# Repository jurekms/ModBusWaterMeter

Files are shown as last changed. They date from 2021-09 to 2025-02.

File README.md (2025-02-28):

# ModBusWaterMeter
Nakładka na wodomierz zliczająca impulsy ,udostępniająca dane za pomocą protokołu MODBUS poprzez interfejs RS485.
Nakładka na wodomierz zliczająca ilość obrotów dwubarwnej tarczy znajdującej się na panelu odczytowym wodomierza. Optyczny układ przystawki oświetla tarczę obrotową wodomierza światłem IR, które jest odbijane (część lustrzana tarczy) lub pochłaniane (część czarna tarczy), odbita wiązka jest rejestrowana przez fototranzystor z którego sygnał analogowy kierowany jest do komparatora okienkowego zbudowanego na układzie LM393. Na wyjściu komparatora pojawia się sygnał wysoki - gdy fototranzystor jest oświetlony światłem odbitym od tarczy lub niski gdy światło jest pochłaniane przez tarczę i nie dociera do fototranzystora. Tak uformowany sygnał kierowany jest do wejścia D0 mikroprocesora 368. Oprogramowanie rejestruje dwa impulsy na każdy obrót tarczy - dwa przejścia lustro->czarny i czarny->lustro, co daje dwa impulsy na jeden litr przepływu.

szczegóły w opisie  (https://github.com/jurekms/ModBusWaterMeter/blob/main/WIKI/readme.pdf)

# ModBusWaterMeter
Pulse counting water meter overlay, providing data via the MODBUS protocol via the RS485 interface. Overlay on the water meter counting the number of revolutions of the two-color dial located on the reading panel of the water meter. The optical system of the attachment illuminates the rotating disc of the water meter with IR light, which is reflected (mirror part of the dial) or absorbed (black part of the dial), the reflected beam is recorded by the phototransistor from which the analog signal is directed to a window comparator built on the LM393 system. At the output of the comparator there is a high signal - when the phototransistor is illuminated by light reflected from the dial or low when the light is absorbed by the dial and does not reach the phototransistor. The signal formed in this way is directed to the D0 input of the microprocessor 368. The software records two pulses for each rotation of the dial - two mirror->black and black-> mirror transitions, which gives two pulses per one liter of flow.

more in  (https://github.com/jurekms/ModBusWaterMeter/blob/main/WIKI/readme.pdf)

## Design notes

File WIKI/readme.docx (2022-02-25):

Projekt przystawki powstał gdy zaszła konieczność wymiany wodomierzy abonenckich z uwagi na upływający okres ważności legalizacji. Wodomierze eksploatowane są w małej wspólnocie mieszkaniowej której jestem członkiem. Obecny system zdalnego odczytu opiera się na wodomierzach wyposażonych w kontaktrony które przełączane są miniaturowym magnesem umieszczonym na jednym z elementów liczydła, daje to dwa impulsy na jeden litr przepływu. Impulsy są zliczane przez dwa liczniki ośmio wejściowe odczytywane i konfigurowane przy pomocy zapisów i odczytów rejestrów za pośrednictwem protokołu MODBUS na magistrali RS-485. Liczniki są odczytywane co jedną minutę a odczyty porównywane z poprzednio odczytaną wartością, jeśli występuje różnica dane umieszczane są w bazie danych wraz z informacją o dacie i godzinie odczytu. System dodatkowo generuje alarmy wysyłając powiadomienia SMSem, w przypadku gdy ciągły pobór przekracza 10 minut, i w przypadku gdy w ciągu doby nie występuje pobór wody. Do tej pory zebrano ponad 650 tysięcy odczytów, co może służyć do dość szczegółowej analizy zużycia wody, a w zestawieniu z informacją o mieszkańcach czy najemcach lokali użytkowych daje możliwość wykonania dość interesujących analiz. Kilkakrotnie udało się zapobiec niekontrolowanemu poborowi wody głównie na wskutek zablokowania lub nieszczelności spłuczki w WC. Cały system powstał po tym jak w wyniku rocznego rozliczenia zużycia wody, wystąpiła znaczna różnica pomiędzy sumą wskazań wodomierzy abonenckich a wodomierzem Miejskiego Wodociągu. Różnica ta osiągnęła prawie 100m3 co wygenerowało prawie 1000 złotych niedopłaty!.

Jak wspomniano w tym roku mija pięcioletni okres legalizacji wodomierzy. Niestety na rynku nie są już dostępne wodomierze z kontaktronowym impulsatorem. Po analizie oferty dotyczącej wodomierzy z zabudowanymi przystawkami impulsowymi okazało się że wodomierz taki to wydatek około 300 zł. Jednocześnie wydaje się że podobny problem związany z wymianą pojawi się za następne pięć lat z uwagi na modułową zabudowę przystawki na wodomierzu.

Powstał pomysł aby na podstawie doświadczeń z poprzednimi wodomierzami i dobrą stabilną praca poprzedniego rozwiązania sprzętowo-programowego opracować przystawkę do wodomierza która będzie rejestrował obroty tarczy w liczydle wodomierza. Opracowano prototyp przystawki zakładanej na wodomierz wyposażony w tarcze, która obracając się generuje podobnie jak wodomierz z kontaktronem dwa impulsy na jeden litr przepływu. Schemat blokowy przedstawia rys.1

Układ optyczny to popularny moduł CNY70 wyposażony w diodę IR i fototranzystor, który umieszczony w odpowiedniej odległości od tarczy obrotowej generuje na wyjściu napięcie zgodnie z obrotami tarczy. Sygnał z tego modułu podawany jest na wejście komparatora okienkowego zbudowanego na układzie LM363. Zastosowanie komparatora zapobiega wzbudzeniu się układu na granicy przejść gdy światło IR jest odbijane i pochłaniane. Na wyjściu komparatora umieszczono układ kształtowania impulsu zbudowany na tranzystorze T1. Tak uformowane impulsy podawane są na wejście D0 mikroprocesora Atmega 386.

Sam program napisany jest jako maszyna stanów. Moduł komunikuje się ze światem zewnętrznym przy pomocy protokołu MODBUS na magistrali RS-485. Jest urządzeniem typu SLAVE. Może być odczytany i zapisany z dowolnej aplikacji pracującej z protokołem MODBUS. W porównaniu do poprzednie realizacji obecny układ został wzbogacony o nowe możliwości. A są to:

- możliwość ustawiania alarmu ciągłego poboru wody wraz z zmianą czasu w którym ten pobór musi wystąpić,
- możliwość ustawiania alarmu braku poboru wody w określonym czasie, alarmy te generowane są w urządzeniu powodując ustawienie odpowiednich rejestrów,
- możliwość sterowania dodatkowym tranzystorem (zwieranie do masy), który może zostać wysterowany po wystąpieniu alarmu lub stan jego może zostać zmieniony przy użyciu aplikacji zewnętrznej, tranzystor można wykorzystać np. do uruchomienia zaworu,
- stan alarmu może być sygnalizowany diodą,
- moduł wyposażony jest w dwie diody zieloną i czerwoną, domyślnie dioda zielona sygnalizuje poprawny stan pracy modułu a jej wyłączenie następuje w momencie transmisji, dioda czerwona sygnalizuje miganiem obrót tarczy (pobór wody), i wystąpienie alarmu, jednak diody te mogą być wygaszone lub zapalone poprzez wysterowanie ich z aplikacji zewnętrznej,
- w konfiguracji modułu można zapisać trzy wskazania wodomierza,
- konfiguracja przystawki po uruchomieniu wczytana zostaje z pamięci stałej EEPROM do pamięci RAM i tam może zostać zmieniona i zapisana ponownie w pamięci stałej,
- na ośmiu 16 bitowych rejestrach zapisana jest etykieta wodomierza dwa znaki w każdym z rejestrów co daje możliwość zapisania 16-to znakowej etykiety,
- na bieżąco można odczytać rejestr liczydła oraz rejestry alarmów,

Funkcjonalności te umożliwiają zastosowanie modułu jako urządzenie samodzielne z okazjonalnym odczytem poprzez RS-485, lub pozwalają zbudować całkiem rozbudowany i funkcjonały system nadzoru zużycia wody w nieruchomości. Z powodzeniem wykorzystuje to rozwiązanie do sterowania systemem nawadniania roślin na działce, można np. bardzo precyzyjnie zadać ilości wody do systemu podlewania kroplowego.

Przystawka składa się z trzech zasadniczych elementów :

- części elektronicznej
- części mechanicznej – obudowa i uchwyt do wodomierzach
- oprogramowania – samego modułu język C, prostej aplikacji do konfiguracji i odczytu język JAVA

Część elektroniczna.

Układ elektroniczny składa się czterech bloków:

- zasilania, opartego na układzie stabilizatora monolitycznego 5V wraz z układem kondensatorów filtrujących i diody zabezpieczającej układ przed pomyłkowy podłączeniem zasilania. Z uwagi na tak wybrany sposób zasilania maksymalne napięcie zasilające to 12V.
- układ komparatora okienkowego wraz z tranzystorem formującym impulsy wyjściowe, zapobiega on powstawaniu oscylacji na wskutek wystąpienia „stanów nieustalonych”.
- układu mikroprocesora, jest to standardowa aplikacja uP Atmega 328, procesor obsługuje sygnał wyjściowy komparatora, oraz steruje diodami świecącymi, tranzystorem oraz zapewnia transmisję MODBUS poprzez interfejs RS-232,
- układ konwertera RS-232/RS-485, zrealizowany w oparciu o układ MAX485 na wejście którego podłączone są linie Tx/Rx uP Atmega, dodatkowo linia PD2 steruje kierunkiem transmisji.

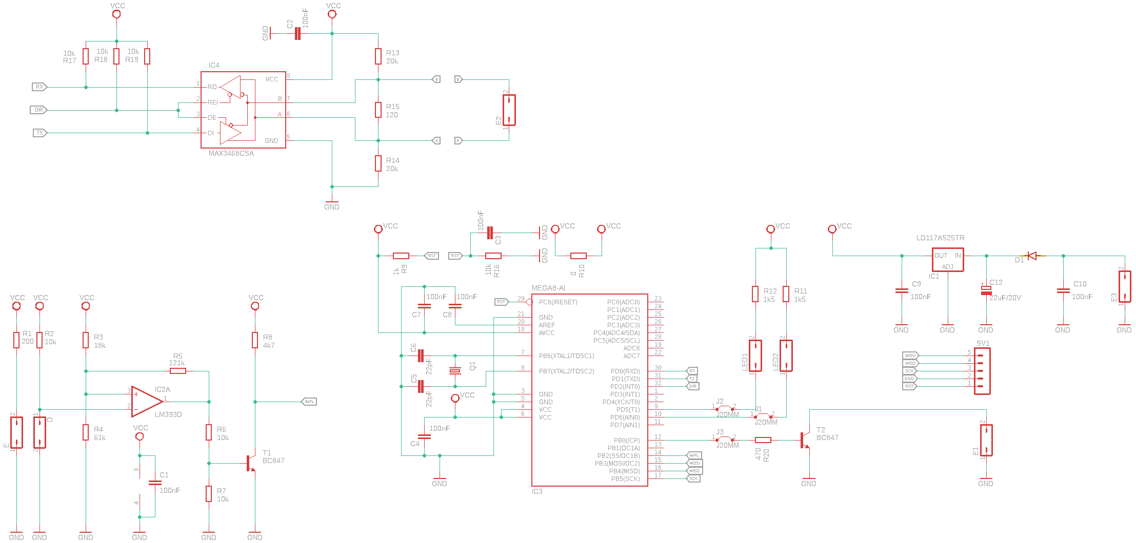
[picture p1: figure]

Układ zmontowany jest na płytce jednostronnej, zaprojektowanej w programie EAGEL w wersji darmowej (z ograniczeniem co do wielkości PCB). Sam płytka fizycznie została wykonana metodą fotochemiczną. Laminat pokryty emulsją światłoczułą został naświetlony na drukarce 3D typu Elegoo Mars . Drukarka ta drukuje za pomocą utrwalania żywicy światłoczułej promieniami UV. Z pojemnika na żywicę „wyciągane” są kolejne warstwy wydruku utrwalane promieniami ultrafioletowymi. W projekcie tym pojemnik na żywice zastąpiono laminatem pokrytym emulsja światłoczułą i wykonano 3 minutowe naświetlnie warstwy. Po około 30 minutach laminat „wywołano” w odpowiednim roztworze, a następnie wytrawiono w wytrawiaczu B327 w temperaturze około 40C. Jakość, powtarzalność i szybkość realizacji jest bardzo dobra. Rozwiązanie to w znakomity sposób przyspiesza realizację prototypów. Największym wyzwaniem jest konwersja płaskiego rysunku płytki PCB do formatu 3D a następnie do formatu STL akceptowalnego przez oprogramowanie drukarki 3D. Płytka przystosowana jest montażu powierzchniowego, elementy bierne są rozmiaru 1210 z uwagi na łatwiejszy montaż. Wszystkie pliki są załączone do projektu. Daje to możliwość wykonania zmian, jak również można wykonać płytkę wspomniana metodą fotochemiczną (załączono gotowy plik STL PCB).

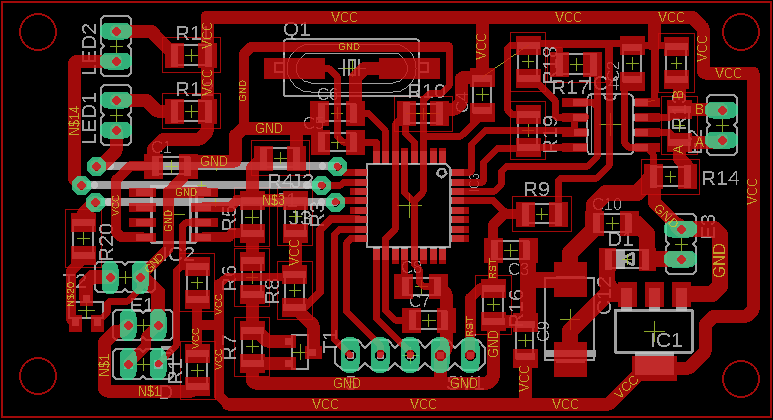
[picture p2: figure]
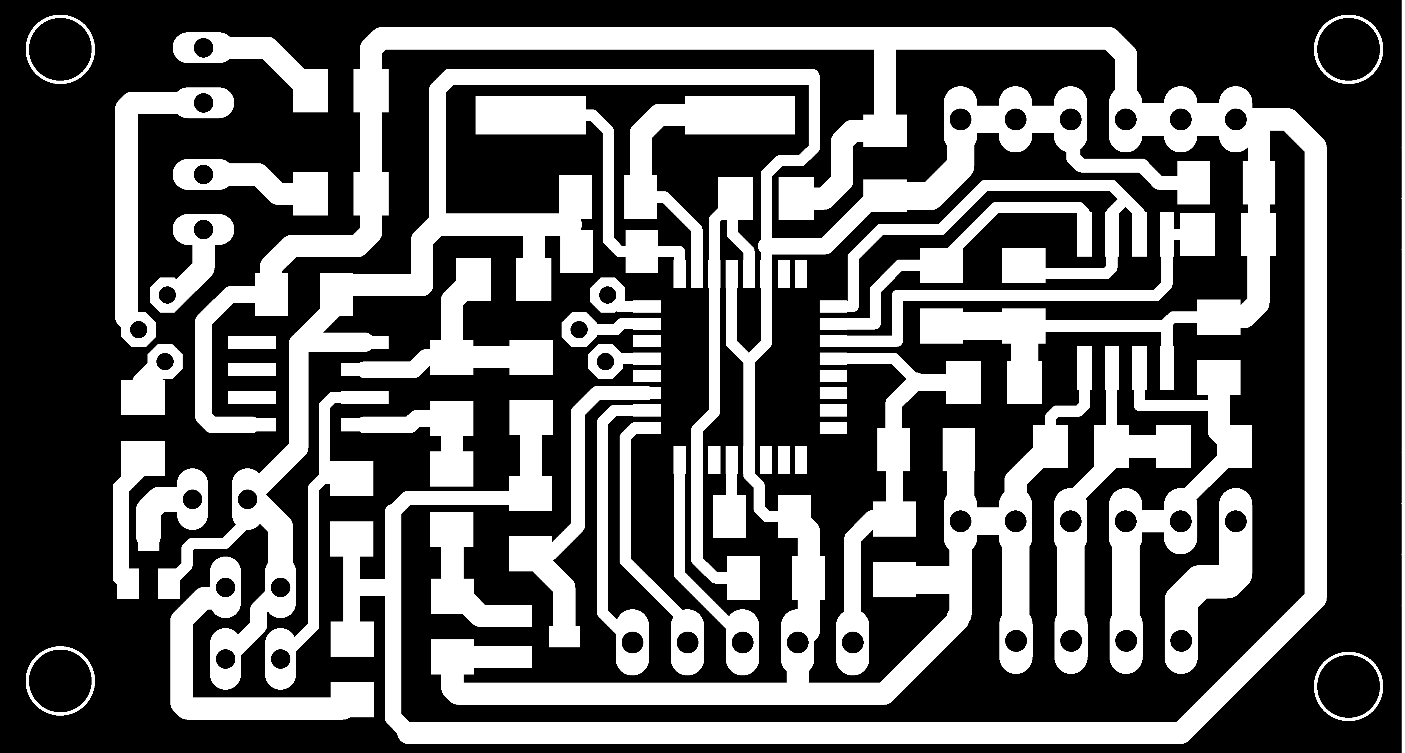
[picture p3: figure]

Część mechaniczna.

Aby moduł można było zamocować na wodomierzu wykonano stosowną obudowę i uchwyt, który służy do zamocowania przystawki na korpusie liczydła. Obudowę zaprojektowano w programie FreeCAD, a wydruk wykonano na drukarce 3D. Wykonano próby z materiałami ABS i PLA, oba spełniają wszystkie wymagania co do elastyczności i trwałości. Plik projektów i pliki STL są załączone do projektu.

Oprogramowanie

Część systemowa.

Oprogramowanie systemowe zostało napisane w języku C na procesor Atmega. Projekt został zrealizowany w środowisku Eclipse. Aplikacja działa w oparciu o maszynę stanów. W aplikacji jest kilka takich maszyn:

- maszyna obsługująca protokół MODBUS ( własna biblioteka uMODBUS),
- maszyna obsługująca sterowanie diodami świecącymi,
- maszyna obsługująca alarmy,
- maszyna obsługująca sterowanie cewkami,

Odczyt wyjścia z przetwornika optycznego i komparatora okienkowego realizowane jest w przerwaniu TIMERA2 co 10ms, jest to wystarczająca częstotliwość dająca możliwość realizacji programowej funkcji „debouncingu”, który dodatkowo (poza komparatorem okienkowym) zapobiega niestabilności układu, a w przypadku podłączenia przetwornika opartego na mechanicznym zwieraniu styków eliminuje drgania styków.

Zastosowanie maszyny stanów pozwoliło na stworzenie wrażenia wielowątkowości, i spowodowało że sam kod jest przejrzysty i łatwy do modyfikacji.

W projekcie zastosowano niewielką bibliotekę obsługującą protokół MODBUS (SLAVE RTU), napisaną na potrzeby poprzedniego projektu. Biblioteka oparta na maszynie stanów i wywołaniu zarejestrowanych funkcji obsługujących poszczególne funkcjonalności protokołu MODBUS.

Mapa rejestrów modułu.

W module zdefiniowano następujące rejestry

Obszar konfiguracji, 32 rejestry szesnastobitowe :

adres MODBUS | ilość rejestrów 16 bitowych | nazwa | opis
40001 - 40008 | 8 | wmLabel | etykieta wodomierza 16 znaków
40009 - 40010 | 2 | wmSerialNumber | numer seryjny tylko cyfry!
40011 | 1 | wmSoftVersion | wersja oprogramowania systemowego
40012 - 40013 | 2 | wmCorrectionCounter | wartość korekty do wykorzystania w oprogramowaniu własnym, np. przy wymianie wodomierza
40014 - 40015 | 2 | wmInitialCounter | wartość początkowa liczydła
40016 - 40017 | 2 | wmStoreCounter | wartość zapisana liczydła
40018 - 40019 | 2 | wmCurrentCounter | aktualna wartość liczydła
40020 - 40021 | 2 | wmPulseCounter | wmPulseCounter = 2 x wmCurrentCounter +/-1
40022 | 1 | wmCheckYear | rok w którym upływa okres legalizacji
40023 | 1 | wmFirstTimeRunFlag | ustawiana na 0xAA oznacza pierwsze uruchomienie
40024 | 1 | wmModbusSlaveAddress | modbus SLAVE adres
40025 | 1 | wmContinuousWaterFlowAlarmAllow | jeśli ustawiony na 1 to alarm o ciągłym poborze wody jest aktywny
40026 | 1 | wmContinuousWaterFlowAlarmTimes | ilość kolejnych okresów w których jeśli wystąpi ciągły przepływ wody to wywołany zostanie alarm
40027 - 40028 | 2 | wmContinuousWaterFlowAlarmPeriod | czas trwania jednego okresu 6000 = 1min
40029 | 1 | wmNoWaterFlowAlarmAllow | jeśli ustawiony na 1 to alarm o braku poboru wody jest aktywny
40030 - 40031 | 2 | wmNoWaterFlowAlarmTime | czas braku poboru wody po którym generowany jest alarm, 1 = 10 ms => 6000 = 1 minute => 8 640 000 = 24h
40032 | 1 | wmOUTTransistorAlarmAllow | jeśli ustawiony jest na 0x0001 każdy alarm ustawia wyście tranzystorowe na stałe, jeśli ustawiony jest na 0x0002 każdy alarm ustawia wyjście tranzystorowe tylko na czas alarmu, jeśli ustawiony jest na 0x0000 alarmy nie powodują zmiany wyjścia tranzystorowego

CDN :)

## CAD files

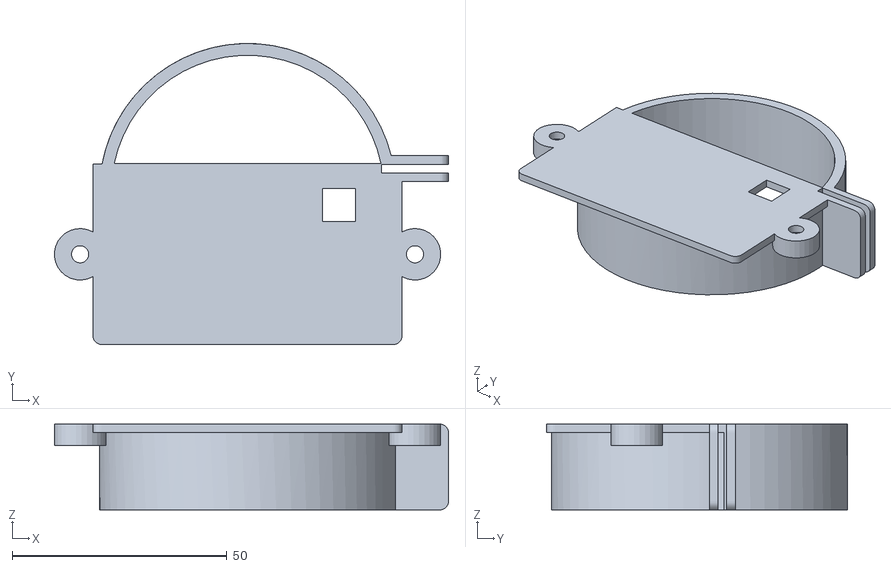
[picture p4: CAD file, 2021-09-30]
3D PRINT CASE/BASE.stl
91.8 x 70.1 x 20.0

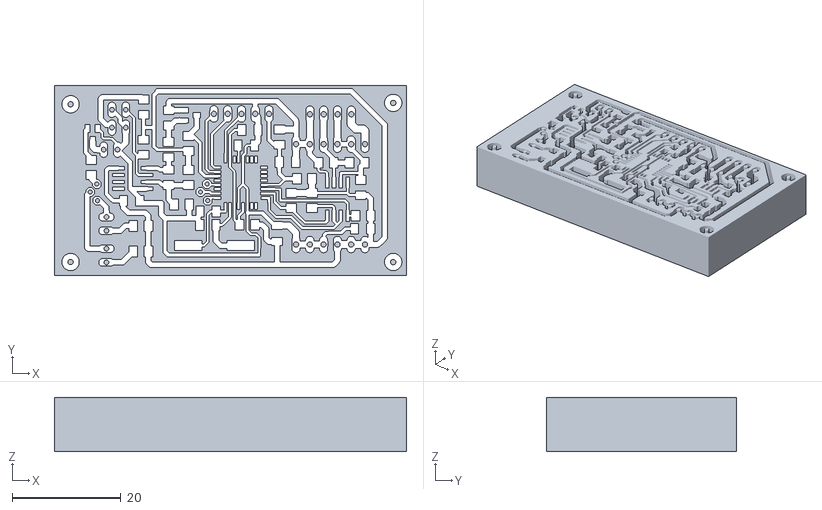
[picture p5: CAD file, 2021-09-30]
PCB/pcb.stl
64.7 x 34.8 x 10.0

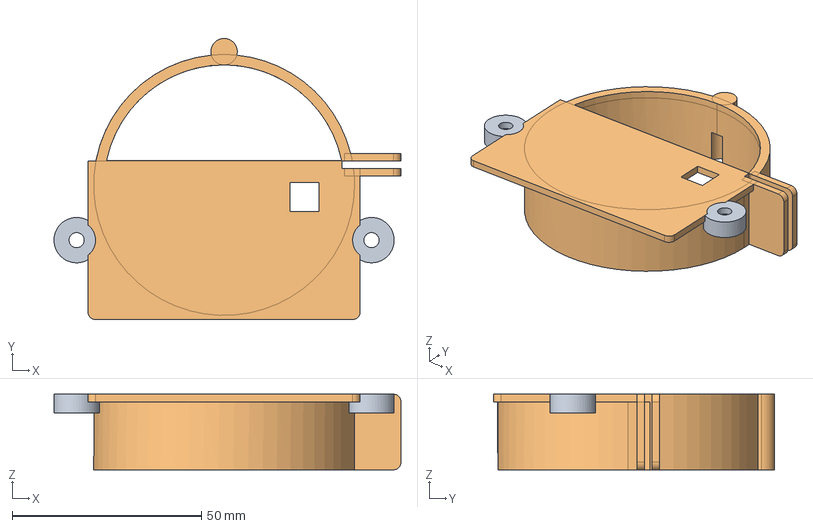
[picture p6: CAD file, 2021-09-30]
3D PRINT CASE/CASE ver 2 in FreeCAD.FCStd
91.8 x 74.4 x 20.0 mm
BASE MOUNT
BASE

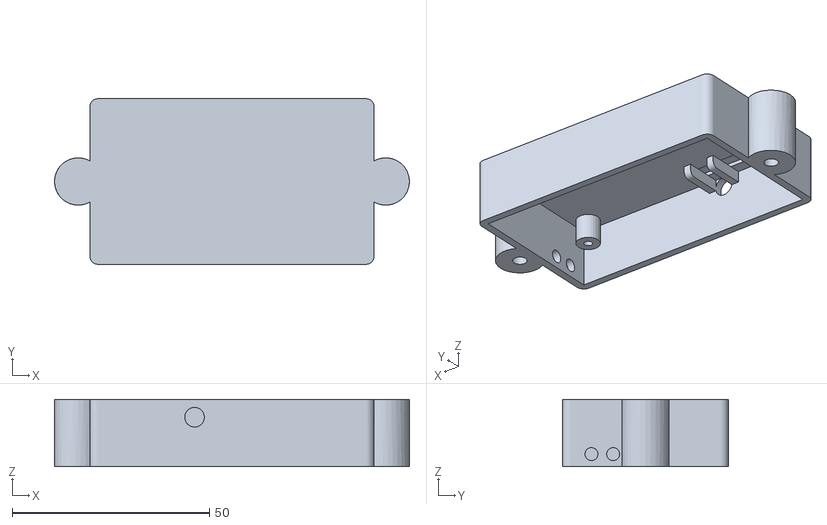
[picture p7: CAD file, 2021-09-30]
3D PRINT CASE/COVER.stl
90.0 x 42.0 x 17.0

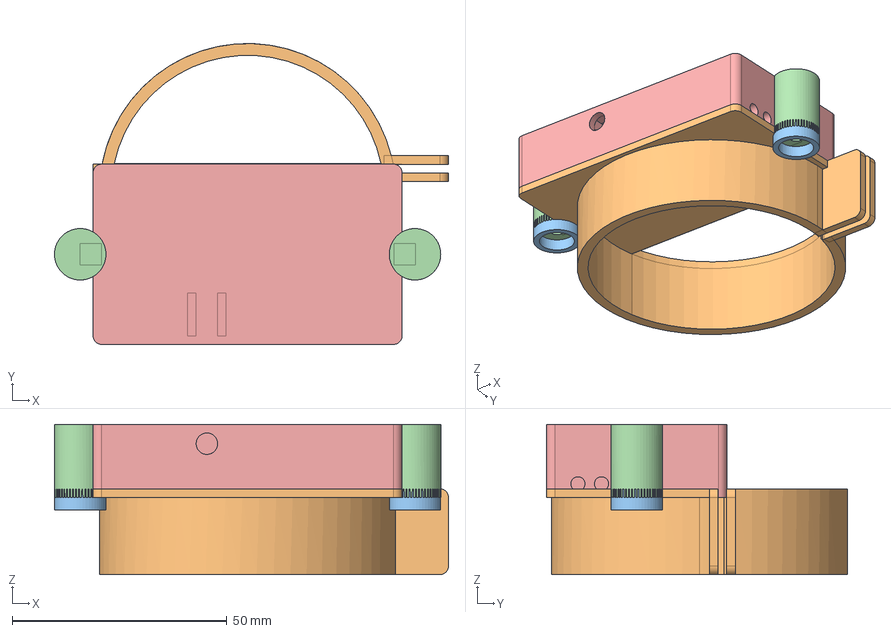
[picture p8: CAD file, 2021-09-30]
3D PRINT CASE/CASE in FreeCAD.FCStd
91.8 x 70.1 x 35.0 mm
PCB MOUNT
BASE
BASE MOUNT
COVER MOUNT
COVER

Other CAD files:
3D PRINT CASE/BASE ver 2.stl

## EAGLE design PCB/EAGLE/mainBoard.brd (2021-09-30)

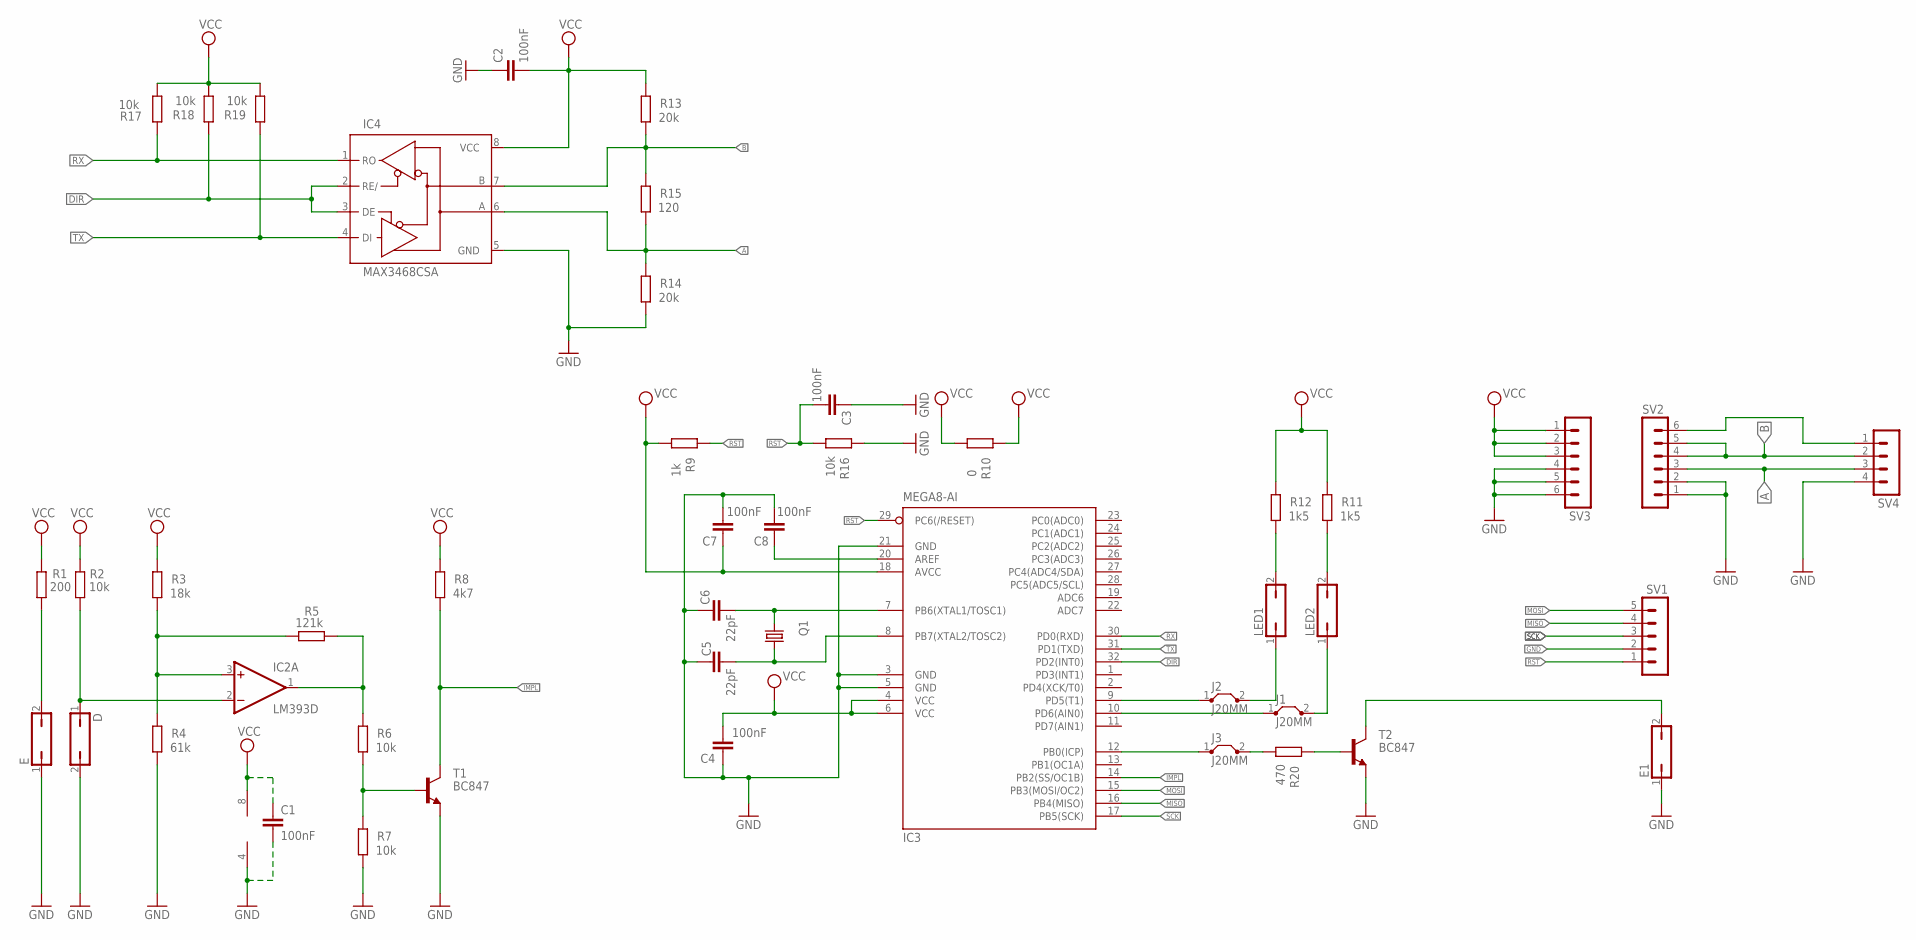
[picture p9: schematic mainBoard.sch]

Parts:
C1, C2, C3, C4, C7, C8: 100nF; C1206K
C5, C6: 22pF; C1206K
D: JP1Q; JP1
E, E1: JP1Q; JP1
IC2: LM393D; SO08
IC3: MEGA8-AI; TQFP32-08
IC4: MAX3468CSA; SO08
J1, J2, J3: J20MM; 20
LED1, LED2: JP1Q; JP1
Q1: CRYSTALSM49; SM49
R1: 200; M1206
R2, R6, R7, R16, R17, R18, R19: 10k; M1206
R3: 18k; M1206
R4: 61k; M1206
R5: 121k; M1206
R8: 4k7; M1206
R9: 1k; M1206
R10: 0; M1206
R11, R12: 1k5; M1206
R13, R14: 20k; M1206
R15: 120; M1206
R20: 470; M1206
SV1: MA05-1
SV2, SV3: MA06-1
SV4: MA04-1
T1, T2: BC847; SOT23

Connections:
A: IC4.6 (A), R14.2, R15.1, SV2.3, SV4.3
B: IC4.7 (B), R13.1, R15.2, SV2.4, SV2.5, SV4.2
DIR: IC3.32 (PD2(INT0)), IC4.2 (RE/), IC4.3 (DE), R18.2
GND: C1.2, C2.1, C3.1, C4.1, C5.1, C6.1, C7.2, C8.2, D.2, E.1, E1.1, IC2.4 (V-), IC3.3 (GND), IC3.5 (GND), IC3.21 (GND), IC4.5 (GND), R4.1, R7.1, R14.1, R16.2, SV1.2, SV2.1, SV2.2, SV3.4, SV3.5, SV3.6, SV4.4, T1.2 (E), T2.2 (E)
IMPL: IC3.14 (PB2(SS/OC1B)), R8.1, T1.3 (C)
MISO: IC3.16 (PB4(MISO)), SV1.4
MOSI: IC3.15 (PB3(MOSI/OC2)), SV1.5
unnamed: E.2, R1.1
unnamed: D.1, IC2.2 (-IN), R2.2
unnamed: IC2.3 (+IN), R3.1, R4.2, R5.2
unnamed: R6.1, R7.2, T1.1 (B)
unnamed: IC2.1 (OUT), R5.1, R6.2
unnamed: SV2.6, SV4.1
unnamed: LED2.2, R11.1
unnamed: LED1.2, R12.1
unnamed: C5.2, IC3.8 (PB7(XTAL2/TOSC2)), Q1.1
unnamed: C8.1, IC3.20 (AREF)
unnamed: C6.2, IC3.7 (PB6(XTAL1/TOSC1)), Q1.2
unnamed: J2.2, LED1.1
unnamed: J1.2, LED2.1
unnamed: IC3.9 (PD5(T1)), J2.1
unnamed: IC3.10 (PD6(AIN0)), J1.1
unnamed: IC3.12 (PB0(ICP)), J3.1
unnamed: J3.2, R20.1
unnamed: E1.2, T2.3 (C)
unnamed: R20.2, T2.1 (B)
RST: C3.2, IC3.29 (PC6(/RESET)), R9.2, R16.1, SV1.1
RX: IC3.30 (PD0(RXD)), IC4.1 (RO), R17.1
SCK: IC3.17 (PB5(SCK)), SV1.3
TX: IC3.31 (PD1(TXD)), IC4.4 (DI), R19.2
VCC: C1.1, C2.2, C4.2, C7.1, IC2.8 (V+), IC3.4 (VCC), IC3.6 (VCC), IC3.18 (AVCC), IC4.8 (VCC), R1.2, R2.1, R3.2, R8.2, R9.1, R10.1, R10.2, R11.2, R12.2, R13.2, R17.2, R18.1, R19.1, SV3.1, SV3.2, SV3.3

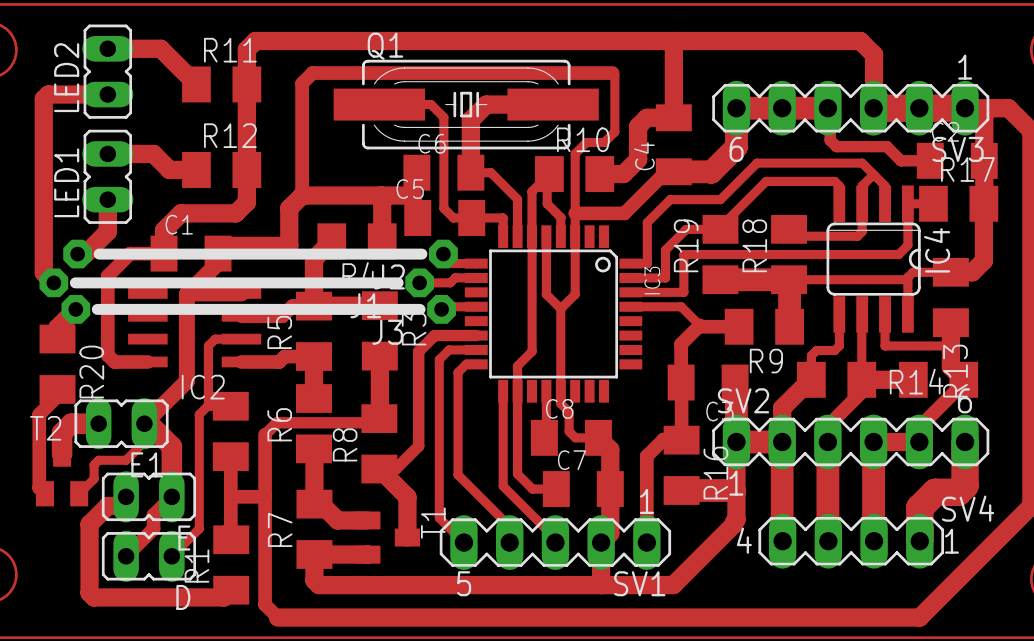
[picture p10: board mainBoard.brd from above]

Board: 2 copper layers, 46 parts (0 on the bottom side), 31 nets.

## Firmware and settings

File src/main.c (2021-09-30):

/*
 * main.c
 *
 *  Created on: 1 kwi 2021
 *      Author: JUREK
 */


#include <avr/io.h>
#include <avr/interrupt.h>

#include "./modbus/mb.h"

#include "waterMeter/waterMeter.h"
#include "waterMeter/LEDStatus.h"
#include "waterMeter/coils.h"
#include "waterMeter/OUTTransistor.h"
#include "waterMeter/alarms.h"
#include "waterMeter/timers.h"
#include "waterMeter/registers.h"




int main(void) {

	/******************************************************************************************************************************************************
	 *
	 * initialize all of modules
	 *
	 *******************************************************************************************************************************************************/

	wmConfigurationInit();
	mbInit(CFG_RAMMEM.configuration.wmModbusSlaveAddress);
	wmDebouncerInit();
	wmAlarmsInit();
	wmLEDSInit();
	wmOUTTransisitorInit();
	wmCoilsInit();
	wmTimersInit();

	/******************************************************************************************************************************************************
	 *
	 * start interrupts
	 *
	 *******************************************************************************************************************************************************/

	sei();


	/******************************************************************************************************************************************************
	 *
	 * start STATE MACINEs
	 *
	 *******************************************************************************************************************************************************/

	while(1) {

		mbPoll();

		wmLEDPoll();

		wmCoilsPoll();

		wmAlarmsPoll();


	}

	return 0;
}

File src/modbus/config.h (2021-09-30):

/*
 * config.h
 *
 *  Created on: 26 lip 2015
 *  Author: Jerzy Maczenski JMS
 */

#ifndef CONFIG_H_
#define CONFIG_H_

// UART parameters
#define UART_SPEED						19200
#define UART_DATA_BITS 					8
#define UART_PARITY  					'n'
#define UART_STOP_BITS 					1

//use RS485?
#define USE_RS485

// define port and pin to change TX/RX of RS485
#define RS485_PORT_DIRECTION			PORTD
#define RS485_DDR_PORT_DIRECTION		DDRD
#define RS485_PIN_DIRECTION 			(1<<PD2)
#define	RS485_PIN_DIRECTION_SET_OUT 	RS485_DDR_PORT_DIRECTION |= RS485_PIN_DIRECTION

// TX/RX of RS485 macros
#define RS485_SET_TX					RS485_PORT_DIRECTION |= RS485_PIN_DIRECTION
#define RS485_SET_RX					RS485_PORT_DIRECTION &= ~RS485_PIN_DIRECTION



// Modbus SLAVE address
//#define	MB_MY_SLAVE_ADDR				192



// Max numer of callback functions
#define MB_MAX_NUMER_CALLBACK_FUNCTIONS	1

#endif /* CONFIG_H_ */

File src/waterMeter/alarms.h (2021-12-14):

/*
 * alarms.h
 *
 *  Created on: 15 kwi 2021
 *      Author: JUREK
 */

#ifndef WATERMETER_ALARMS_H_
#define WATERMETER_ALARMS_H_


/******************************************************************************************************************************************************
 *
 * functions declarations
 *
 *******************************************************************************************************************************************************/

void wmAlarmsInit(void);
void wmAlarmsPoll(void);

/******************************************************************************************************************************************************
 *
 *
 * macros use in order to set or reset bits in WM_ALARM_LED GLOBAL VARIABLE
 *
 *******************************************************************************************************************************************************/


#define WM_ALARM_NO_WATER_FLOW_LED_ON				WM_ALARM_LED |= 1
#define WM_ALARM_CONTINUOUS_WATER_FLOW_ON			WM_ALARM_LED |= 2


#define WM_ALARM_NO_WATER_FLOW_LED_OFF				WM_ALARM_LED &= ~1
#define WM_ALARM_CONTINUOUS_WATER_FLOW_LED_OFF		WM_ALARM_LED &= ~2


volatile extern uint8_t WATER_METER_IS_WATER_FLOW_FLAG;

#endif /* WATERMETER_ALARMS_H_ */
